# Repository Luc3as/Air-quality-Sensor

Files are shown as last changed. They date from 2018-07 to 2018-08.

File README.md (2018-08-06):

# Air quality sensor
This simple, fancy looking, ESP8266 based sensor measures values of CO2 and TVOC air pollutants.
As output there is addressable RGB led strip, and/or optional OLED display which can show real time levels.

## Material needed
* [Wemos D1 mini](https://www.aliexpress.com/item/ESP8266-ESP12-ESP-12-WeMos-D1-Mini-WIFI-Dev-Kit-Development-Board-NodeMCU-Lua/32653918483.html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,searchweb201602_4_10152_10151_10065_10068_10344_10342_10343_10340_10341_10696_10084_10083_10618_10307_10820_10821_10303_10846_10059_100031_524_10103_10624_10623_10622_10621_10620,searchweb201603_25,ppcSwitch_5&algo_expid=7c525067-46ab-4a80-baab-f36e6cb5dd58-0&algo_pvid=7c525067-46ab-4a80-baab-f36e6cb5dd58&transAbTest=ae803_1&priceBeautifyAB=0)
* [CCS811 sensor](https://www.aliexpress.com/item/CJMCU-811-CCS811-Carbon-Monoxide-CO-VOCs-Air-Quality-Numerical-Gas-Sensors/32784803629.html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,searchweb201602_4_10152_10151_10065_10068_10344_10342_10343_10340_10341_10696_10084_10083_10618_10307_10820_10821_10303_10846_10059_100031_524_10103_10624_10623_10622_10621_10620,searchweb201603_25,ppcSwitch_5&algo_expid=90061718-43a7-4c82-83e5-2a1a41b8e246-0&algo_pvid=90061718-43a7-4c82-83e5-2a1a41b8e246&transAbTest=ae803_1&priceBeautifyAB=0)
* [WS2812b led strip](https://www.aliexpress.com/item/1m-4m-5m-WS2812B-Smart-led-pixel-strip-Black-White-PCB-30-60-144-leds-m/2036819167.html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,searchweb201602_4_10152_10151_10065_10068_10344_10342_10343_10340_10341_10696_10084_10083_10618_10307_10820_10821_10303_10846_10059_100031_524_10103_10624_10623_10622_10621_10620,searchweb201603_25,ppcSwitch_5&algo_expid=e920b19e-1960-4e49-b688-bdefa83688ed-0&algo_pvid=e920b19e-1960-4e49-b688-bdefa83688ed&transAbTest=ae803_1&priceBeautifyAB=0)
* [Optional OLED display](https://www.aliexpress.com/item/Free-Shipping-White-Blue-Whiteand-Blue-color-0-96-inch-128X64-OLED-Display-Module-For-arduino/32713614136.html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,searchweb201602_4_10152_10151_10065_10068_10344_10342_10343_10340_10341_10696_10084_10083_10618_10307_10820_10821_10303_10846_10059_100031_524_10103_10624_10623_10622_10621_10620,searchweb201603_25,ppcSwitch_5&algo_expid=a29b31fa-7b49-45dd-bc4d-7a5f6978be6e-2&algo_pvid=a29b31fa-7b49-45dd-bc4d-7a5f6978be6e&transAbTest=ae803_1&priceBeautifyAB=0)

And of course some soldering iron and generic tools.

### 3D printed case
You can download latest version of case on [thingiverse](https://www.thingiverse.com/thing:2997734).
There will be updated side cover with hole for display soon. 

## Schematic

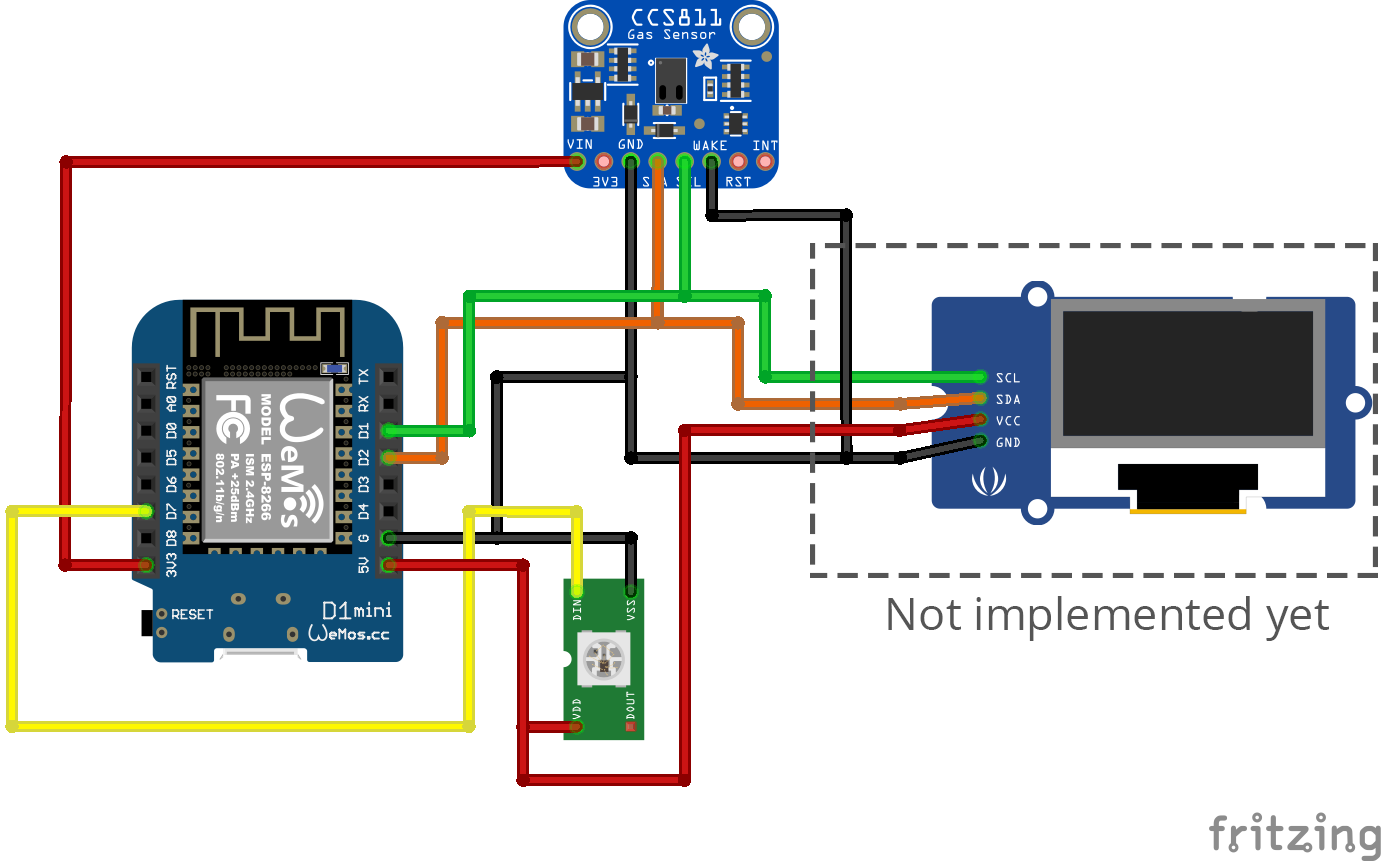
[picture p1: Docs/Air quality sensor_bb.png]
Connection diagram


## Final sensor assembly
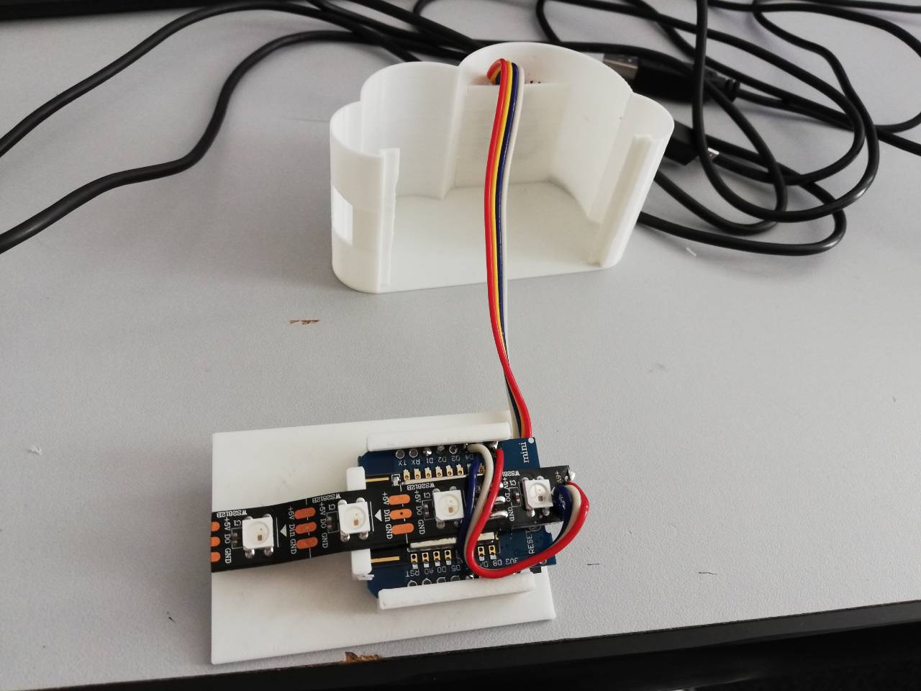
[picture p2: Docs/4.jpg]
wiring

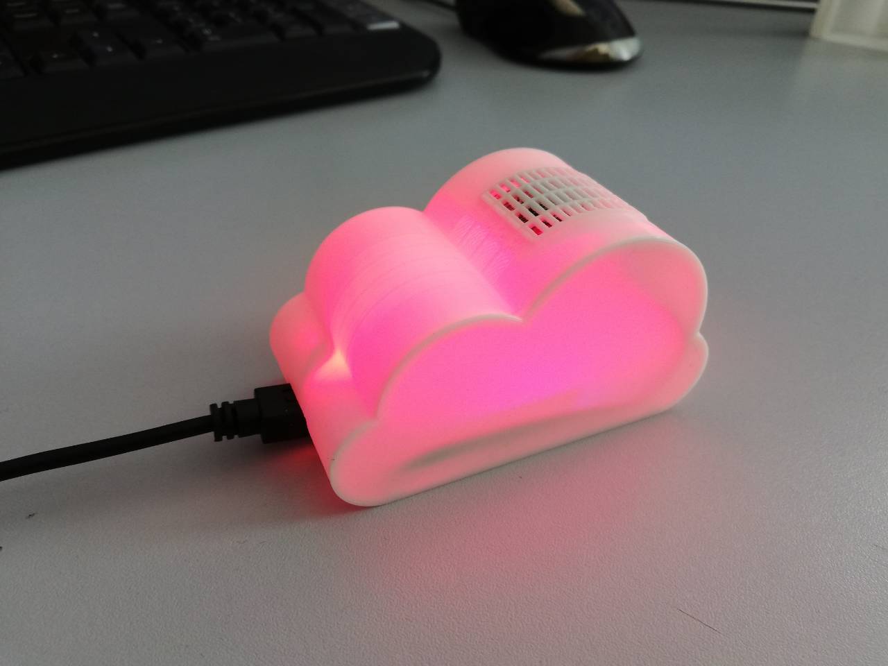
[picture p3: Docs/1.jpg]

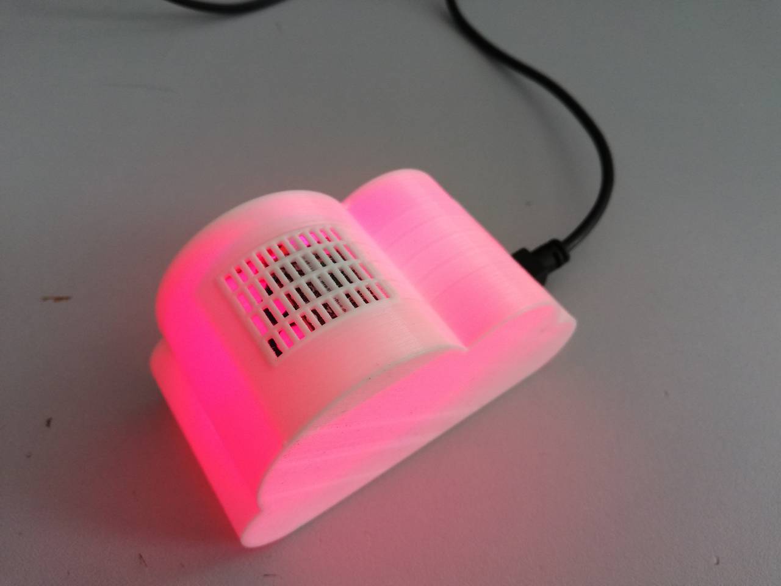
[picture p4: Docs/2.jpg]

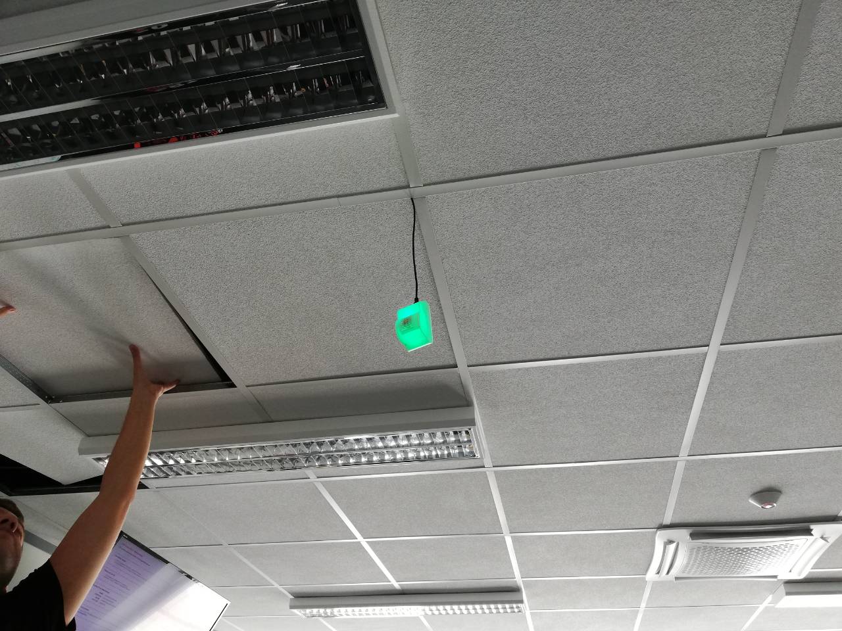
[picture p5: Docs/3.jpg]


## Configuration
There is source code attached, I am using WiFi Manager, so after burning firmware, there will be WiFi hotspot, you can connect with password "config123".
After that you should open address 192.168.4.1 and there will be configuration manager where you can enter details about your SSID, password, MQTT broker address, port, username and password, as well as MQTT topic where should sensor publish the data.

I connected 4 pieces of WS2812b LEDS, if you have different number, you should edit following line in main.cpp and compile project in platformio.
```c++
#define NUMPIXELS      4
```

## Measuring
I don't know it I received bad piece of CCS811 sensor, but I spent few nights discovering why it stops reading data after few hours of operation, and only  thing that helped to recover it was to unplug power source and plug it back.
I realized that in default it takes reading every second. So I found out how to set to take reading every 10 seconds with line
```c++
ccs.setDriveMode(CCS811_DRIVE_MODE_10SEC);
```
I am taking 6 readings, calculate average and then print and publish data, so sensor sends data every minute.

## Burning the firmware
I precompiled firmware for Wemos D1 mini you can download it here 

You can use attached burner from easy esp, you just have to select COM port of ESP and select burn.

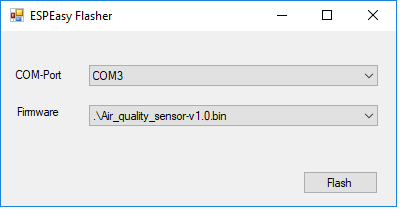
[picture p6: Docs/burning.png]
Burning the firmware


## HomeAssistant example configuration
This example shows sensor configuration for reading ppm values, and it shows other values as json attributes so it can be viewed after opening sensor details. 
```python
# CO2 sensor
  - platform: mqtt
    state_topic: 'stat/air-quality-monitor'
    name: 'CO2 sensor'
    unit_of_measurement: 'ppm'
    value_template: '{{ value_json.eCO2 }}'
    json_attributes:
      - TVOC
      - temperature
```

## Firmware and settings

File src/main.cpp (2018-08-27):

#include <FS.h>                   //this needs to be first, or it all crashes and burns...
#include <ESP8266WiFi.h>          //https://github.com/esp8266/Arduino
//needed for library
#include <DNSServer.h>
#include <ESP8266WebServer.h>
#include <WiFiManager.h>          //https://github.com/tzapu/WiFiManager
#include <ArduinoJson.h>          //https://github.com/bblanchon/ArduinoJson
#include <PubSubClient.h>
#include "Adafruit_CCS811.h"
#include <Adafruit_NeoPixel.h>


//flag for saving data
bool shouldSaveConfig = false;

//define your default values here, if there are different values in config.json, they are overwritten.
//char mqtt_server[40];
char mqtt_server[40] = "192.168.1.249";
char mqtt_port[6] = "1883";
char mqtt_user[20] = "user";
char mqtt_pass[20] = "password";
char mqtt_topic[50] = "stat/air-quality-monitor";

#define ADDR      0x5A
//#define ADDR      0x5B

#define LED_PIN       13 // D7 where WS2812b LEDS are connected
// How many NeoPixels are attached to the Arduino?
#define NUMPIXELS      4

// D5 Reset

const int sclPin = 5; // D1
const int sdaPin = 4; //  D0

unsigned long  lastMeasurement;
const int delayval = 25; // delay for neopixel

long eCO2 = 0;
long TVOC = 0;
float temp;
int avgeCO2, avgTVOC, i, j = 0, k;
int sumeCO2 = 0;
int sumTVOC = 0;
enum { N = 6 }; // Number of readings to make smooting(average).
//             Default reading every 10 seconds and sends every minute

WiFiClient espClient;
PubSubClient client(espClient);
Adafruit_CCS811 ccs;
Adafruit_NeoPixel pixels = Adafruit_NeoPixel(NUMPIXELS, LED_PIN, NEO_GRB + NEO_KHZ800);

//callback notifying us of the need to save config
void saveConfigCallback () {
  Serial.println("Should save config");
  shouldSaveConfig = true;
}


void setup() {

  // put your setup code here, to run once:
  Serial.begin(115200);
  Serial.println("Hold your hats");

  pixels.begin(); // This initializes the NeoPixel library.
  pixels.setBrightness(255);
  pixels.show();

  //clean FS for testing
  //SPIFFS.format();

  //read configuration from FS json
  Serial.println("mounting FS...");

  if (SPIFFS.begin()) {
    Serial.println("mounted file system");
    if (SPIFFS.exists("/config.json")) {
      //file exists, reading and loading
      Serial.println("reading config file");
      File configFile = SPIFFS.open("/config.json", "r");
      if (configFile) {
        Serial.println("opened config file");
        size_t size = configFile.size();
        // Allocate a buffer to store contents of the file.
        std::unique_ptr<char[]> buf(new char[size]);

        configFile.readBytes(buf.get(), size);
        DynamicJsonBuffer jsonBuffer;
        JsonObject& json = jsonBuffer.parseObject(buf.get());
        json.printTo(Serial);
        if (json.success()) {
          Serial.println("\nparsed json");
          strcpy(mqtt_server, json["mqtt_server"]);
          strcpy(mqtt_port, json["mqtt_port"]);
          strcpy(mqtt_user, json["mqtt_user"]);
          strcpy(mqtt_pass, json["mqtt_pass"]);
          strcpy(mqtt_topic, json["mqtt_topic"]);

        } else {
          Serial.println("failed to load json config");
        }
      }
    }
  } else {
    Serial.println("failed to mount FS");
  }
  //end read



  // The extra parameters to be configured (can be either global or just in the setup)
  // After connecting, parameter.getValue() will get you the configured value
  // id/name placeholder/prompt default length
  WiFiManagerParameter custom_mqtt_server("server", "mqtt server", mqtt_server, 40);
  WiFiManagerParameter custom_mqtt_port("port", "mqtt port", mqtt_port, 6);
  WiFiManagerParameter custom_mqtt_user("user", "mqtt user", mqtt_user, 20);
  WiFiManagerParameter custom_mqtt_pass("pass", "mqtt pass", mqtt_pass, 20);
  WiFiManagerParameter custom_mqtt_topic("topic", "mqtt topic", mqtt_topic, 50);

  //WiFiManager
  //Local intialization. Once its business is done, there is no need to keep it around
  WiFiManager wifiManager;

// Reset Wifi settings for testing
//  wifiManager.resetSettings();

  //set config save notify callback
  wifiManager.setSaveConfigCallback(saveConfigCallback);

  //set static ip
  //  wifiManager.setSTAStaticIPConfig(IPAddress(10,0,1,99), IPAddress(10,0,1,1), IPAddress(255,255,255,0));

  //add all your parameters here
  wifiManager.addParameter(&custom_mqtt_server);
  wifiManager.addParameter(&custom_mqtt_port);
  wifiManager.addParameter(&custom_mqtt_user);
  wifiManager.addParameter(&custom_mqtt_pass);
  wifiManager.addParameter(&custom_mqtt_topic);

  //reset settings - for testing
  //wifiManager.resetSettings();

  //set minimum quality of signal so it ignores AP's under that quality
  //defaults to 8%
  //wifiManager.setMinimumSignalQuality();

  //sets timeout until configuration portal gets turned off
  //useful to make it all retry or go to sleep
  //in seconds
  //wifiManager.setTimeout(120);

  //fetches ssid and pass and tries to connect
  //if it does not connect it starts an access point with the specified name
  //here  "AutoConnectAP"
  //and goes into a blocking loop awaiting configuration
  if (!wifiManager.autoConnect("Air-quality-monitor", "config123")) {
    Serial.println("failed to connect and hit timeout");
    delay(3000);
    //reset and try again, or maybe put it to deep sleep
    ESP.reset();
    delay(5000);
  }

  //if you get here you have connected to the WiFi
  Serial.println("connected...yeey :)");

  //read updated parameters
  strcpy(mqtt_server, custom_mqtt_server.getValue());
  strcpy(mqtt_port, custom_mqtt_port.getValue());
  strcpy(mqtt_user, custom_mqtt_user.getValue());
  strcpy(mqtt_pass, custom_mqtt_pass.getValue());
  strcpy(mqtt_topic, custom_mqtt_topic.getValue());

  //save the custom parameters to FS
  if (shouldSaveConfig) {
    Serial.println("saving config");
    DynamicJsonBuffer jsonBuffer;
    JsonObject& json = jsonBuffer.createObject();
    json["mqtt_server"] = mqtt_server;
    json["mqtt_port"] = mqtt_port;
    json["mqtt_user"] = mqtt_user;
    json["mqtt_pass"] = mqtt_pass;
    json["mqtt_topic"] = mqtt_topic;

    File configFile = SPIFFS.open("/config.json", "w");
    if (!configFile) {
      Serial.println("failed to open config file for writing");
    }

    json.printTo(Serial);
    json.printTo(configFile);
    configFile.close();
    //end save
  }

  Serial.println("Local IP");
  Serial.println(WiFi.localIP());
  const uint16_t mqtt_port_x = atol( mqtt_port );
  client.setServer(mqtt_server, mqtt_port_x);

  if(!ccs.begin()){
    Serial.println("Failed to start sensor! Please check your wiring.");
  } else {
  }



  //calibrate temperature sensor
  while(!ccs.available()) {
    float temp = ccs.calculateTemperature();
    ccs.setTempOffset(temp - 25.0);
  }
  Wire.setClockStretchLimit( 460L );
  ccs.setDriveMode(CCS811_DRIVE_MODE_10SEC);
} // End Setup

// NEOPIXEL
// Fill the dots one after the other with a color
void colorWipe(uint32_t c, uint8_t wait) {
  for(uint16_t i=0; i<pixels.numPixels(); i++) {
      pixels.setPixelColor(i, c);
      pixels.show();
      delay(wait);
  }
}

void reconnect() {
  // Loop until we're reconnected
  while (!client.connected()) {
    Serial.print("Attempting MQTT connection...");
    // Attempt to connect
    // If you do not want to use a username and password, change next line to
    // if (client.connect("ESP8266Client")) {
    if (client.connect("AirQualitySensor", mqtt_user, mqtt_pass)) {
      Serial.println("connected");
    } else {
      Serial.print("failed, rc=");
      Serial.print(client.state());
      Serial.println(" try again in 5 seconds");
      // Wait 5 seconds before retrying
      for (int b=1; b<=5; b++) {     // Start our for loop
        colorWipe(pixels.Color(0, 0, 255), 10);
        delay(500);
        colorWipe(pixels.Color(0, 0, 0), 10);
        delay(500);
      }

    }
  }
}

void loop() {
  // put your main code here, to run repeatedly:
  if (!client.connected()) {
    reconnect();
  }
  client.loop();  // check for MQTT messages

  long now = millis();
///////////////////////////////////////////////////////////////////////////////////////////////////////
  if( now - lastMeasurement > 10000) {
    lastMeasurement = now;
    eCO2 = 0;
    TVOC = 0;
    if (j < N) {
      temp = ccs.calculateTemperature();
      if(!ccs.readData() ){
        eCO2 = ccs.geteCO2(); //returns eCO2 reading
        TVOC = ccs.getTVOC(); //return TVOC reading
        if ( eCO2 > 65000 ) {
          Serial.println("ERROR reading from sensor!");
          delay(3000);
          eCO2 = 0;
        }
        Serial.print("CO2: ");
        Serial.print(eCO2);
        Serial.print("ppm, TVOC: ");
        Serial.print(TVOC);
        Serial.print("ppb   Temp:");
        Serial.println(temp);
        }
      else{
        Serial.println("ERROR reading from sensor!");
        delay(3000);
      }


      // Add numbers to average
       sumeCO2 += eCO2;
       sumTVOC += TVOC;

      j++;
    } else { // We have N averaged measurements, print it and reset counters
      avgeCO2 = sumeCO2 / N;
      avgTVOC = sumTVOC / N;
      Serial.print("Average eCO2: ");
      Serial.println(avgeCO2);
      Serial.print("Average TVOC: ");
      Serial.println(avgTVOC);

      if( avgeCO2 > 0 ) {
        // Prepare a JSON payload string
        String payload = "{";
        payload += "\"eCO2\":"; payload += avgeCO2; payload += ",";
        payload += "\"TVOC\":"; payload += avgTVOC; payload += ",";
        payload += "\"temperature\":"; payload += temp;
        payload += "}";

        // Convert payload
        char attributes[100];
        payload.toCharArray( attributes, 100 );
        // Send MQTT message
        Serial.print("Sending MQTT message: ");
        Serial.println(payload);
        client.publish(mqtt_topic, attributes , false);

      }

      // Set color of neopixel
      if (avgeCO2 >= 1500) {
        colorWipe(pixels.Color(255, 0, 0), 50);
      } else if (avgeCO2 < 1500 && avgeCO2 >= 1000 ) {
        colorWipe(pixels.Color(255, 119, 0), 50);
      } else if (avgeCO2 < 1000  && avgeCO2 > 0 ) {
        colorWipe(pixels.Color(0, 255, 0), 50);
      } else {
        colorWipe(pixels.Color(0, 0, 0), 50);
      }

      j=0;
      sumeCO2 = 0;
      sumTVOC = 0;
    }
  } // End if(now - lastMeasurement > 1000)
} // End LOOP

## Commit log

2018-07-20 added whole code
    [Air quality sensor.fzz]
2018-08-27 Fixed stability (I hope)
    [main.cpp]
2018-08-27 Added clock stretch limit
    Added clock strech limit for I2C bus.
